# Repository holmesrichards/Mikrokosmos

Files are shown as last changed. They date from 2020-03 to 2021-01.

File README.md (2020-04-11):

# Mikrokosmos
Kosmo format version of Music Thing Modular's Mikrophonie Eurorack synthesizer module (https://github.com/TomWhitwell/Mikrophonie). Almost no change to the circuit (other than the diodes protecting the power supply), but PCB is laid out differently and there is a Kosmo-size front panel inspired by the Eurorack original.

BOM is here: https://github.com/holmesrichards/Mikrokosmos/blob/master/PCB/Mikrokosmos.md

## Build notes

Mostly the build is pretty standard and straightforward.

All PCB mounted parts go on the top side EXCEPT the pot. Don’t be like me and absent mindedly solder it to the same side as everything else. In the completed module the parts other than the pot are on the side of the board facing away from the panel.

The piezo disc mounts to the back of the panel behind the scratch panel, below the screw hole. I used a Scotch double stick adhesive strip and that seemed to work fine.

Solder the red piezo lead to the switch terminal on the Mic In jack. (You’ll probably need to lengthen the piezo wires.) Wire jack grounds to one of the ground terminals on the board and the tip terminals to the Mic In + and Output + terminals. I specified 2 pin Molex headers for the jack connections but on mine I just soldered the wires.

The bottom of the PCB is secured to the panel via the pot. Use a 10 mm M3 spacer and two M3 screws to secure the top of the PCB.

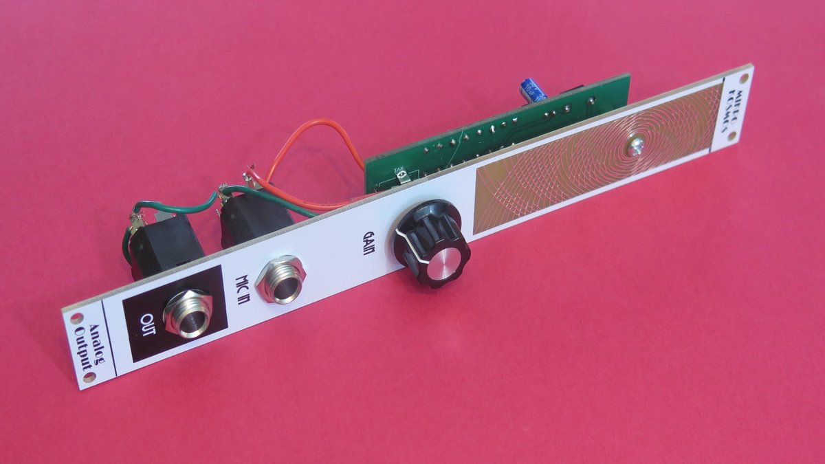
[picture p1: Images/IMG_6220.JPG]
Module


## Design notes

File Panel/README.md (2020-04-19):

# Mikrokosmos panel files

Aside from the usual files created with KiCad:

- mikrokosmos_panel.kicad_pcb
- mikrokosmos_panel.pro
- mikrokosmos_panel.sch

there is a directory of Gerber/drill files:

- MikrokosmosGerbers

and the following associated with panel artwork:

- mikrokosmos_panel_inkscape_silk.png

    This is the silkscreen artwork
 
- artc.png

    This is the copper layer artwork
 
These were converted using the Bitmap to Component Converter to make
 
- art2.kicad_mod

    Silkscreen footprint
  
- artc.kicad_mod

    Copper footprint
  
The converter doesn't let you specify a copper layer so I used a text editor search and replace to make all layer references become F.Cu . These then were added to a new footprint library:

- Panel.pretty

The two footprints were placed and aligned in Pcbnew, and then I drew a rectangle using the Add a graphic polygon tool in the front mask layer over the copper artwork to make a rectangular gap in the front solder mask.

Due to the complexity of the copper artwork it takes a while for Pcbnew to render, for example, a 3d view, or to do copper fills. Be patient.

Other files here:

- mikrokosmos_panel_inkscape.png

    A rendering of the module from Inkscape

- README.md

    This file

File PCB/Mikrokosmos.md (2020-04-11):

# Mikrokosmos

Sat 11 Apr 2020 01:22:39 PM EDT

Generated from schematic by Eeschema 5.1.5-52549c5~84~ubuntu18.04.1

**Component Count:** 19

| Value | Qty | Part | Description | Vendor |
| ----- | --- | ---- | --- | --- |
| C1, C2 | 2 | 10uF | Polarized capacitor |  |
| C4, C5 | 2 | 0.1uF | Unpolarized capacitor |  |
| D1, D2 | 2 | 1N4148 | 100V 0.15A standard switching diode, DO-35 |  |
| D3, D4 | 2 | 1N5817 | 20V 1A Schottky Barrier Rectifier Diode, DO-41 |  |
| J1 | 1 | EURO_PWR_2x5 | Eurorack style 2x5 pin power header |  |
| J4, J5 | 2 | Molex 2 pin | Generic connector, single row, 01x02, script generated (kicad-library-utils/schlib/autogen/connector/) |  |
| R5 | 1 | 1M | Resistor |  |
| R8 | 1 | 10k | Resistor |  |
| R10 | 1 | 56k | Resistor |  |
| R12, R14 | 2 | 2.2k | Resistor |  |
| R16 | 1 | 220R | Resistor |  |
| RV1 | 1 | 50k | Potentiometer |  |
| U2 | 1 | TL072 | Dual Low-Noise JFET-Input Operational Amplifiers, DIP-8/SOIC-8 |  |
    
*Additional parts not on schematic:*

| Qty | Part | Description |
| --- | ---- | --- |
| 2 | 1/4" | Jack (switched) |
| 1 | 10 mm x M3 | Spacer |
| 2 | M3 | Screw |
| 1 | 20 mm | Piezo disc |
| 1 | | Knob |

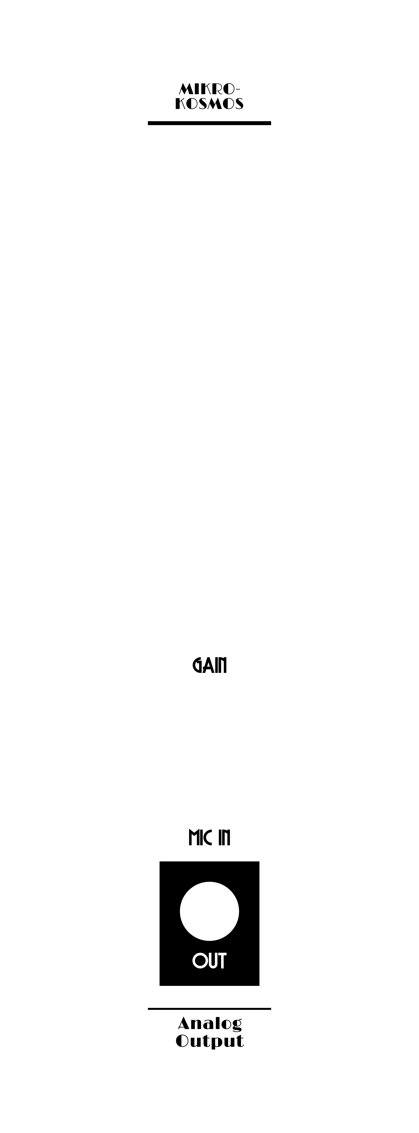
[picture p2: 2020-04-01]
Mikrokosmos-inverted/Panel/mikrokosmos_panel_inkscape_silk.png

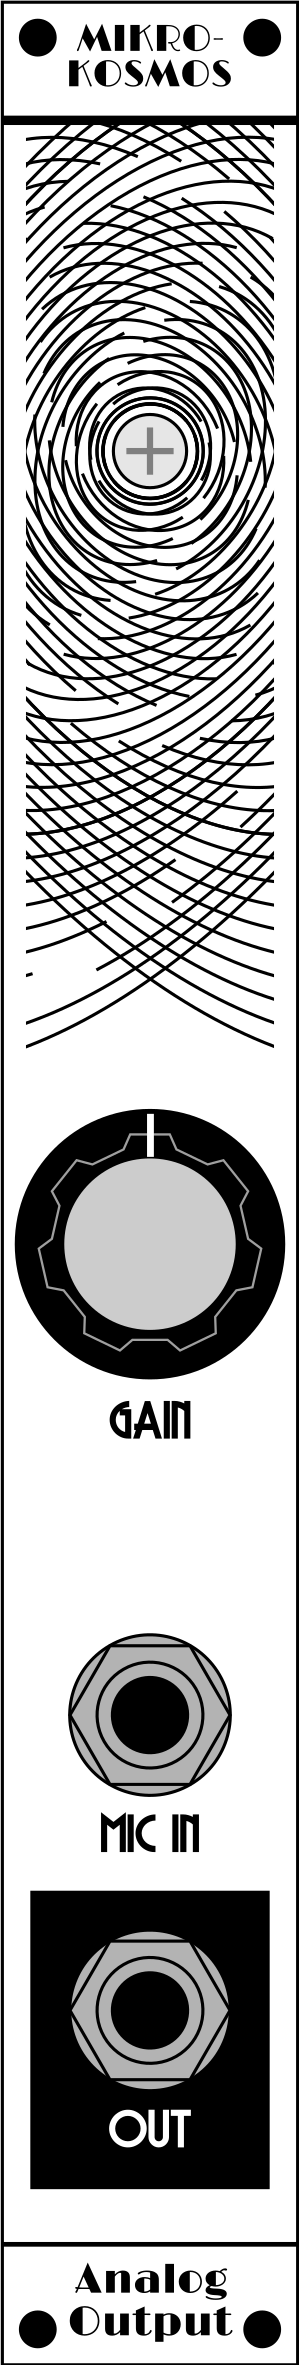
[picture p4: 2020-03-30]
Panel/mikrokosmos_panel_inkscape.png

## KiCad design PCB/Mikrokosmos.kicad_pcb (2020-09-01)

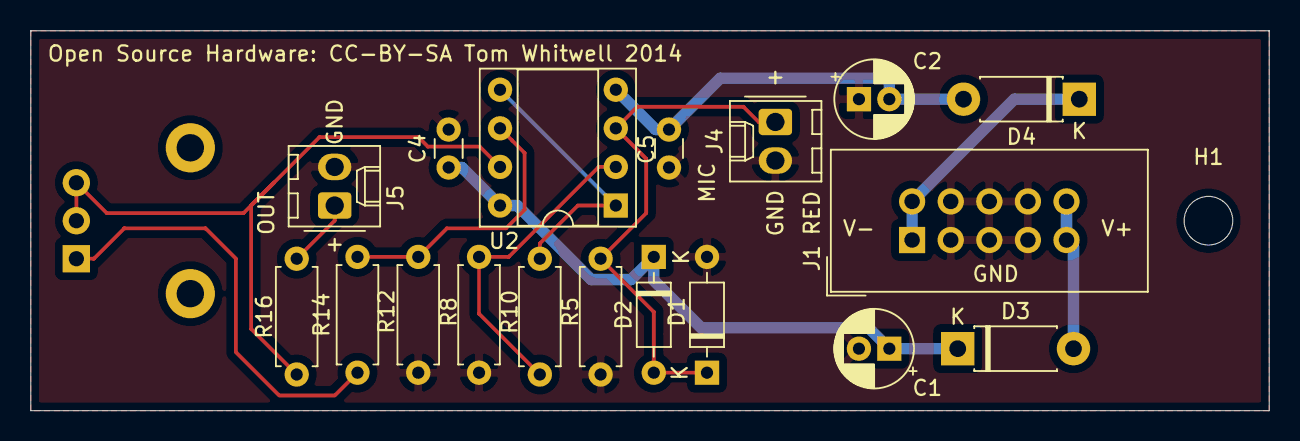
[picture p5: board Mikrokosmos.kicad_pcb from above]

Board: 2 copper layers, 81.5 x 25.0 mm, 20 parts (1 on the bottom side), 12 nets.

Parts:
C1, C2: 10uF; CP_Radial_D5.0mm_P2.00mm
C4, C5: 0.1uF; C_Disc_D3.0mm_W1.6mm_P2.50mm
D1, D2: 1N4148; D_DO-35_SOD27_P7.62mm_Horizontal
D3, D4: 1N5817; D_DO-41_SOD81_P7.62mm_Horizontal
H1: MountingHole; MountingHole_3.2mm_M3
J1: EURO_PWR_2x5; Eurorack_Power_Header_Shrouded
J4, J5: Molex 2 pin; Molex_KK-254_AE-6410-02A_1x02_P2.54mm_Vertical
R5: 1M; R_Axial_DIN0207_L6.3mm_D2.5mm_P7.62mm_Horizontal
R8: 10k; R_Axial_DIN0207_L6.3mm_D2.5mm_P7.62mm_Horizontal
R10: 56k; R_Axial_DIN0207_L6.3mm_D2.5mm_P7.62mm_Horizontal
R12, R14: 2.2k; R_Axial_DIN0207_L6.3mm_D2.5mm_P7.62mm_Horizontal
R16: 220R; R_Axial_DIN0207_L6.3mm_D2.5mm_P7.62mm_Horizontal
RV1: 50k; Potentiometer_Alpha_RD901F-40-00D_Single_Vertical_CircularH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
U2: TL072; DIP-8_W7.62mm_Socket

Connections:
+12V: C1.1, C4.1, D1.1, D3.1, U2.8
-12V: C2.2, C5.2, D4.2, U2.4
/MIC+: D1.2, D2.1, J4.1, R5.1, U2.3
GND: C1.2, C2.1, C4.2, C5.1, D2.2, J1.3, J1.4, J1.5, J1.6, J1.7, J1.8, J4.2, J5.2, R5.2, R8.2, R12.2
unnamed: D3.2, J1.9, J1.10
unnamed: D4.1, J1.1, J1.2
unnamed: J5.1, R16.1
unnamed: R10.1, U2.1, U2.5
unnamed: R8.1, R10.2, U2.2
unnamed: R12.1, R14.2, U2.6
unnamed: R14.1, RV1.1
unnamed: R16.2, RV1.2, RV1.3, U2.7

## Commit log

2020-03-30 Initial versions, PCB and Panel
    [Mikrokosmos-B_Cu.gbr, Mikrokosmos-B_Mask.gbr, Mikrokosmos-B_Paste.gbr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]
2020-04-01 Connect plane to ground via jacks
    [Mikrokosmos.kicad_pcb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]
2020-04-10 Fab layer tweaks
    [Mikrokosmos.kicad_pcb]
2020-04-11 BOM update
2020-04-11 BOM link
2020-04-11 Clean up BOM
2020-04-11 Markdown BOM
    [Mikrokosmos.sch]
2020-04-11 Link to Markdown BOM
2020-04-12 Move global library to local
    [Mikrokosmos.sch]
2020-04-16 Add info on schematic
    [Mikrokosmos.sch]
2020-04-27 Front Cu fill
    [mikrokosmos_panel-B_Cu.gbr, mikrokosmos_panel-B_Mask.gbr, mikrokosmos_panel-B_Paste.gbr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]
2020-09-01 Gerbers to a folder
    [Mikrokosmos-B_Cu.gbr, Mikrokosmos-B_Mask.gbr, Mikrokosmos-B_Paste.gbr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]
2020-10-25 Update .gitignore, Gerbers
    [mikrokosmos_panel-B_Cu.gbr, mikrokosmos_panel-B_Mask.gbr, mikrokosmos_panel-B_Paste.gbr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]
2021-01-02 Inverted panel
    [Mikrokosmos.kicad_pcb, mikrokosmos_panel.kicad_pcb]

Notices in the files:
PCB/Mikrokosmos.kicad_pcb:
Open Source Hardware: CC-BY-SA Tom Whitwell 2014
